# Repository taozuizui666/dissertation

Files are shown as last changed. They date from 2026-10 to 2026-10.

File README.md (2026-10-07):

# **dissertation**

*a self-driving car project based on AI model*

author ： TAO RAN

## 数据训练与模型部署

将采集的操作记录放进根目录 `dataset/`，每行应为 200 个雷达距离加一个操作标签。
正式训练入口为 `software/MLcode/train_model.py`，完成清理、K 特征选择、训练、导出和同步。
K、雷达点数、路径及清理参数集中在脚本顶部。

```bash
python software/MLcode/train_model.py
```

成功后生成 `software/ML_model/randomForest.h` 并备份、同步到
`software/C_code/selfdrive/main/randomForest.h`，打开对应 `main.ino` 编译上传。
模型头文件和训练输出属于生成产物，不手动修改，也不提交到 Git。
首次获取工程时，需要先准备数据并运行训练脚本，生成模型后再编译固件。
本机已配置 `python` 使用 Python 3，并安装用户级训练和 Notebook 依赖。
如需补装全部依赖，在项目根目录执行：

```bash
python -m pip install --user -r software/MLcode/requirements-notebook.txt
```

默认需要 `g++` 校验导出模型。
其他环境的安装和配置详见 [训练说明](software/MLcode/README.md)。

想逐步理解数据如何变成模型，可打开 [教学 Notebook](software/MLcode/training_walkthrough.ipynb)。
选择 `/usr/bin/python3` 内核，逐格运行；默认用临时模拟数据，不覆盖正式模型。

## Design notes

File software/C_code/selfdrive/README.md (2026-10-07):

# Teensy 4.0 自动驾驶程序

在 Arduino IDE 中打开 `main/main.ino`，开发板选择 **Teensy 4.0**，
USB Type 选择 **Serial**，然后编译、上传。

## 文件与依赖

- `main.ino`：读取雷达、提取特征、运行随机森林、控制车轮。
- `Lidar.h` / `Lidar.cpp`：基于 Teensy 数据采集项目的本地雷达驱动，使用
  `Serial2`、115200 波特率和标准 5 字节扫描点协议。
- `control_slide.h` / `control_slide.cpp`：沿用 Teensy 数据采集程序的左右轮
  控制公式及左轮补偿值 10，增加 PWM 的 0–255 限幅。
- `randomForest.h`：训练生成的模型及 `ModelConfig` 输入配置、类别到指令映射。
  由训练脚本同步，不手动修改或提交到 Git；首次编译前需生成该文件。

需要安装 Arduino IDE 的 Teensy 开发板支持包。此项目不需要外部
`RPLidarDriver`、`SoftwareSerial`、SD 或 SPI 库。

## 接线

沿用 `collecting_data/main_lidar_SD_test -teensy -lidar.h/main` 的接线：

| 设备信号 | Teensy 4.0 引脚 |
| --- | --- |
| 雷达 TX | 7（Serial2 RX） |
| 雷达 RX | 8（Serial2 TX） |
| 雷达电机控制 | 9（PWM） |
| 左轮驱动控制 | 14（PWM） |
| 右轮驱动控制 | 15（PWM） |
| 错误指示 LED | 2 |
| 就绪指示 LED | 3 |
| 雷达、车轮驱动器 GND | 与 Teensy GND 共地 |

引脚 0/1 的 `Serial1` 在本程序中未使用，可以保留原来的蓝牙接线，
但本程序不读取蓝牙指令。`Serial` 是电脑 USB 调试接口。
车轮和雷达电机通过已有驱动电路控制；电机供电不能直接接 GPIO。
Teensy 4.0 输入不耐受 5V，UART 信号应与其 3.3V 电平兼容。
参见 [PJRC 串口引脚说明](https://www.pjrc.com/teensy/td_uart.html) 和
[Teensy 4.0 硬件说明](https://www.pjrc.com/store/teensy40.html)。

## 运行与参数

上电时先停止车轮，启动雷达。首次取得全部 K 个有效特征后，自动开始
行驶；无需连接电脑。先架空车轮检查左右轮方向和转向，再落地测试。

`main.ino` 顶部可修改：

| 参数 | 默认值 | 含义 |
| --- | --- | --- |
| `CAR_SPEED` | 100 | 车轮基础 PWM |
| `STEERING_SENSITIVITY` | 2 | Teensy 原采集程序的转向灵敏度 |
| `LIDAR_MOTOR_PWM` | 200 | 雷达电机 PWM |
| `CONTROL_INTERVAL_MS` | 150 | 模型推理和车轮控制间隔 |
| `FEATURE_TIMEOUT_MS` | 500 | 任一模型输入过期后的停车阈值 |

红色/错误指示引脚 2：启动扫描失败时每 500 ms 翻转；特征缺失或
过期时保持高电平。引脚 3：全部模型输入有效且未过期时保持高电平。
启动扫描失败后，检查接线并重启开发板；运行中短暂断流停车后，
全部特征重新有效时自动恢复行驶。
串口监视器每约 500 ms 输出一次 `steering=...`。

## 模型输入约定

分辨率、距离上界、采集扇区、K 和特征索引均读取 `randomForest.h` 的
`ModelConfig`。距离单位为毫米，保持采集程序的整数角度转换。
模型返回类别索引，通过 `ModelConfig::commandForClass()` 转为真实操作指令后
再控制车轮，因此支持训练标签不连续的情况。

在 dissertation 根目录运行 `python3 software/MLcode/train_model.py` 即可重新训练
并同步模型，K 等参数在该脚本顶部修改。详见 [训练说明](../../MLcode/README.md)。
模型头文件属于生成产物，Git 不跟踪；首次获取工程时需要先准备数据并生成模型。

请保持雷达安装方向与训练数据一致。重新训练时，使用 `MLcode/train_model.py`
生成并同步完整模型，确保森林、特征索引及指令映射一起更新。
雷达驱动沿用参考项目的标准扫描协议，不代表支持所有 RPLIDAR 型号。

## 验证

已使用本机 Teensy 1.62.0 开发板支持包，按
`teensy:avr:teensy40:usb=serial` 完整编译通过。
主机模拟测试覆盖扫描响应超时、分段扫描点、无效角度、特征完整性、
数据过期停车、PWM 限幅和 `millis()` 回绕。
尚未执行实物上传和行驶验证，转向效果取决于已有模型和电机标定。

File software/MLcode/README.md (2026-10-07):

# 操作数据训练与部署

正式训练入口是 `train_model.py`，数据清理、K 特征选择、训练、导出及固件同步均由它完成。
全部常用配置集中在文件顶部，用大写常量和中文注释分组。

本机已将 `~/bin/python` 链接到 `/usr/bin/python3`，训练及 Notebook 依赖已安装到
用户级 Python 3 环境。在 dissertation 根目录直接执行：

```bash
python software/MLcode/train_model.py
```

当前终端刷新配置、检查版本及依赖：

```bash
source ~/.bashrc
hash -r
python --version
python -m pip check
```

## 依赖补装

依赖已经安装，正常运行直接使用 `python`。requirements 文件保留用于补装和记录版本范围。
`python -m pip` 使用当前 Python 对应的安装工具。

只补装训练依赖：

```bash
python -m pip install --user -r software/MLcode/requirements.txt
```

训练和 Notebook 的全部依赖：

```bash
python -m pip install --user -r software/MLcode/requirements-notebook.txt
```

`requirements-notebook.txt` 包含 `requirements.txt`，无需分别安装两遍。
需要 Python 3.9 或更新版本、训练依赖和 `g++`。Windows 使用已安装的 Python 3，
并在 `CXX` 配置可用的 GNU C++ 编译器路径。
无编译器时可以显式关闭 `VERIFY_CPP_EXPORT`，报告会标记未执行该检查。
脚本不自动安装依赖，也不自动烧录开发板。

## 逐步学习 Notebook

打开 [training_walkthrough.ipynb](training_walkthrough.ipynb)，在 VS Code 中选择
`/usr/bin/python3` 内核，再从上到下运行单元格。本机已安装 Notebook 依赖，
如需补装，使用上面的 `requirements-notebook.txt` 安装命令。

Notebook 分步展示原始格式、清理统计、X/y、文件分组、ANOVA F 特征评分、K 维输入、
训练与验证、混淆矩阵、最终重训、类别映射、头文件生成和 C++ 预测核对。
它导入正式脚本的函数，并核对展开的训练步骤与正式 `train()` 的结果一致。

默认 `USE_DEMO_DATA=True`，即使 dataset 为空也能运行，并有意加入损坏行展示清理原因。
将其改为 `False` 后读取真实 dataset。两种模式的学习输出均保存在临时目录，不覆盖
正式输出和固件模型。模拟数据的成绩不代表小车效果；正式生成与同步仍使用 `train_model.py`。

## 顶部配置

| 配置 | 默认值 / 作用 |
| --- | --- |
| `K` | 8 个特征 |
| `LIDAR_POINT_COUNT` | 200，必须与采集程序分箱数一致 |
| `INPUT_DIR` | dissertation/dataset，递归读取 `.txt`、`.csv`，不区分扩展名大小写 |
| `OUTPUT_DIR` | software/ML_model |
| `FIRMWARE_HEADER` | software/C_code/selfdrive/main/randomForest.h |
| `USE_FRONT_SECTOR_ONLY` | True，与当前采集程序的扇区限制一致 |
| `MAX_DISTANCE_MM` | 10000，不包含上界 |
| `CLEAN_*` | 整数检查、全零帧过滤、零值比例、文件内去重、录制标签过滤 |
| `TRAIN_LABELS` | 0–15；如需训练直行类别，加入 201 |
| `LABEL_REMAP` | 默认空；`{201: 10}` 将直行并入等效的转向指令 10 |
| `N_ESTIMATORS` / `MAX_DEPTH` | 88 / 3 |
| `TEST_SIZE` / `SPLIT_GAP_ROWS` | 0.2 / 10 |
| `VERIFY_CPP_EXPORT` / `CXX` | 默认用 g++ 编译并核对导出模型 |
| `VERIFY_TEENSY_BUILD` | 默认 False；设 True 并配置 Arduino CLI 后，在覆盖模型前检查整套固件编译 |
| `SYNC_TO_FIRMWARE` | 默认 True，验证成功后备份并同步 |

输入必须无表头，每行是 `d0,d1,...,d199,command`，共 201 列。
末列使用真实蓝牙操作指令，不能通过文件名生成类别。`255` 是开始录制标志，
不作为训练标签；`200` 在当前采集程序中会关闭录制，正常不会写入。
采集只更新索引 0–49 和 151–199，其余列为零，不因这些零删除正常行。
距离数组保留未更新的旧值，记录不是保证全部角度新鲜的完整扫描。
改变分辨率或采集扇区时，需要重新采集对应格式的数据，不能仅修改 Python 配置。

清理报告记录每个文件的列数分布、保留行数和各删除原因。选中特征中的零值默认进一步
排除，以符合固件需要有效距离输入的约定；这一阶段的删除数写入训练报告。

## 运行和输出

```bash
python software/MLcode/train_model.py --k 12
python software/MLcode/train_model.py --clean-only
python software/MLcode/train_model.py --no-sync
```

还可临时指定 `--input-dir`、`--output-dir`、`--firmware-header`。相对路径以
dissertation 为基准，不依赖当前工作目录。输出目录不能放在输入目录内部。

输出包括：

- `randomForest.h`：森林代码、分辨率、扇区、K、原始特征索引、类别到指令映射。
- `data_cleaned.csv`：清理后完整输入，仍是距离列加标签，无表头。
- `clean_report.json`：清理统计。
- `feature_scores.csv`：非常量候选特征的 ANOVA F 分数和选中标志，索引对应原始列。
- `training_report.json`：配置、特征、类别、划分、准确率、混淆矩阵、分类报告、转向容差准确率、导出检查及头文件 SHA-256。
- `randomForest.joblib`：最终 Python 模型及特征、类别配置。
- `backups/<UTC时间>/`：被替换的旧模型，分别保存输出目录和固件目录中的版本。

多文件按文件分组验证，单文件按时间切分并隔开若干相邻帧。特征选择仅使用训练部分；
验证后冻结特征，在全部有效数据上重训最终森林。报告指标来自验证阶段，不是最终森林
在其训练数据上的成绩。如果某类只出现在验证部分，流程报错，需补充采集或调整划分。
将不同独立采集记录保存成不同文件，避免把同一记录的复制件当作独立验证数据。

新头文件直接保存 sklearn 的叶节点类别概率，按森林平均概率预测，保留 `Eloquent::ML::Port::RandomForest`
接口。默认 C++ 检查覆盖数据样本、随机输入和树阈值边界，并核对真实指令与完整概率。
所有检查在临时目录完成，成功后才替换输出及固件模型，写入失败会恢复已替换文件。

根目录 dataset 为空时，不训练或替换模型。`randomForest.h` 和训练输出均为生成产物，
由脚本生成、备份和同步，不手动修改或提交到 Git。`ML_model/` 仅提交目录说明。
首次获取工程时，先准备数据并运行训练脚本，生成完整模型头文件后再编译固件。

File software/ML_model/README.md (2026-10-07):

# 模型输出

运行 `../MLcode/train_model.py` 后，清理数据、特征评分、评估报告、Python 模型及
`randomForest.h` 生成到这里，头文件自动同步到 `../C_code/selfdrive/main/`。
配置和操作说明见 [MLcode/README.md](../MLcode/README.md)。

本目录中的模型、清理数据和评估报告均为生成产物，由脚本管理，不手动修改或提交到 Git。
此目录只提交 README。固件目录中的 `randomForest.h` 同样由训练脚本生成和同步。

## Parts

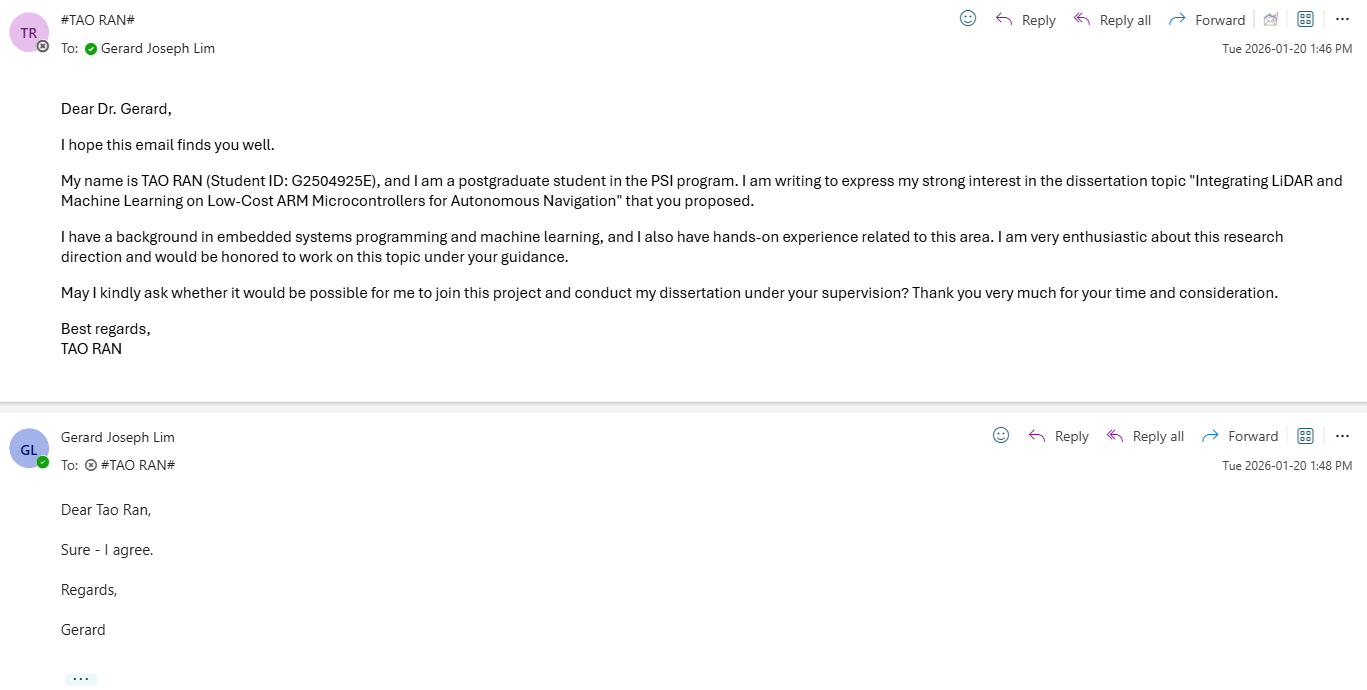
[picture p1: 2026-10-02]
article/TAO RAN_G2504925E_Topic_Integrating LiDAR and Machine Learning on Low-Cost ARM Microcontrollers for Autonomous Navigation.png

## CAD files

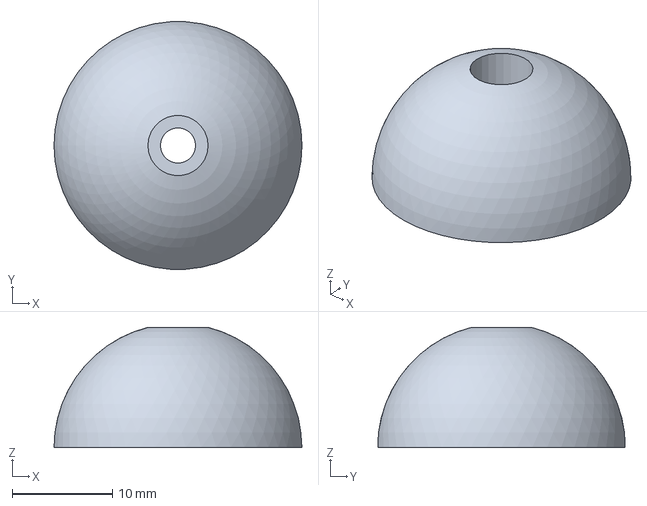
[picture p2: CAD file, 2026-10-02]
hardware/3Dmodels/caster_wheel.3mf
24.7 x 24.7 x 12.0 mm

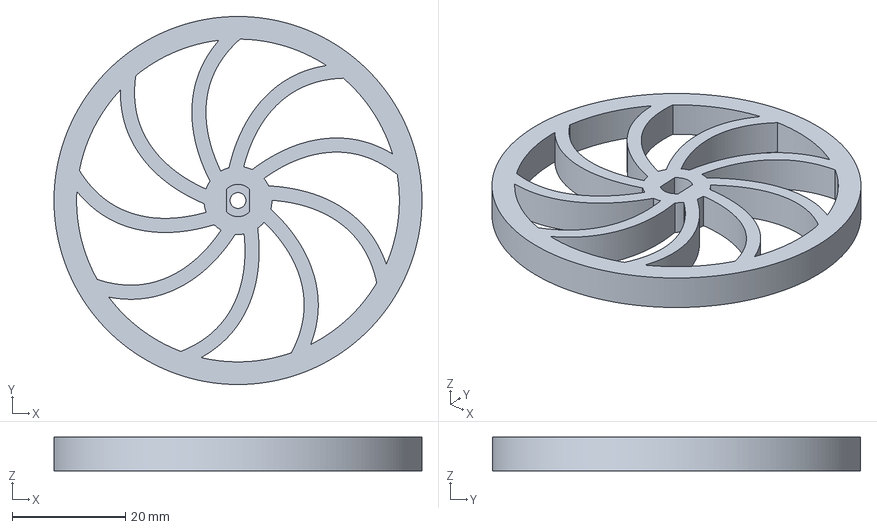
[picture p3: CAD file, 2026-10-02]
hardware/3Dmodels/nikodembartnik-11-tt_motor_wheel.3mf
65.0 x 65.0 x 6.00 mm

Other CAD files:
hardware/3Dmodels/zhijia.gcode.3mf
hardware/3Dmodels/nikodembartnik-48-rplidar_holder.gcode.3mf
hardware/3Dmodels/holder_16pair.gcode.3mf
hardware/3Dmodels/holder.gcode.3mf
hardware/3Dmodels/motor_holder_right.gcode.3mf
hardware/3Dmodels/zhijia2.gcode.3mf

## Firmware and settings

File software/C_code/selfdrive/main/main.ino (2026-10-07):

#include <Arduino.h>
#include "Lidar.h"
#include "control_slide.h"
#include "randomForest.h"

#if !defined(ARDUINO_TEENSY40)
#error "Select Teensy 4.0 in Tools > Board."
#endif

// Same wiring as the Teensy Lidar.h data-collection sketch.
// Lidar TX -> Teensy pin 7 (RX2); Lidar RX -> pin 8 (TX2).
constexpr uint8_t LIDAR_MOTOR_PIN = 9;
constexpr uint8_t LEFT_MOTOR_PIN = 14;
constexpr uint8_t RIGHT_MOTOR_PIN = 15;
constexpr uint8_t ERROR_LED_PIN = 2;
constexpr uint8_t READY_LED_PIN = 3;

constexpr int CAR_SPEED = 100;
constexpr int STEERING_SENSITIVITY = 2;
constexpr uint8_t LIDAR_MOTOR_PWM = 200;
constexpr uint32_t USB_BAUD = 115200;
constexpr uint32_t CONTROL_INTERVAL_MS = 150;
constexpr uint32_t FEATURE_TIMEOUT_MS = 500;
constexpr uint32_t POINT_TIMEOUT_MS = 5;
// Training inputs and class commands travel together with the model header.
constexpr uint16_t LIDAR_RESOLUTION = ModelConfig::LIDAR_RESOLUTION;
constexpr uint16_t MAX_DISTANCE_MM = ModelConfig::MAX_DISTANCE_MM;
constexpr uint16_t FEATURE_COUNT = ModelConfig::FEATURE_COUNT;
constexpr auto &FEATURE_INDICES = ModelConfig::FEATURE_INDICES;

Lidar lidar;
Eloquent::ML::Port::RandomForest classifier;
uint16_t distances[LIDAR_RESOLUTION] = {};
uint32_t featureUpdatedAt[FEATURE_COUNT] = {};
bool featureSeen[FEATURE_COUNT] = {};
bool lidarReady = false;
uint32_t lastControlAt = 0;
uint32_t lastDebugAt = 0;

bool featuresAreFresh(uint32_t now) {
    for (uint16_t i = 0; i < FEATURE_COUNT; ++i) {
        if (!featureSeen[i] ||
            static_cast<uint32_t>(now - featureUpdatedAt[i]) >= FEATURE_TIMEOUT_MS) {
            return false;
        }
    }
    return true;
}

void setup() {
    analogWriteResolution(8);
    pinMode(LIDAR_MOTOR_PIN, OUTPUT);
    pinMode(LEFT_MOTOR_PIN, OUTPUT);
    pinMode(RIGHT_MOTOR_PIN, OUTPUT);
    pinMode(ERROR_LED_PIN, OUTPUT);
    pinMode(READY_LED_PIN, OUTPUT);
    stop_CS(LEFT_MOTOR_PIN, RIGHT_MOTOR_PIN);
    analogWrite(LIDAR_MOTOR_PIN, 0);
    digitalWrite(ERROR_LED_PIN, LOW);
    digitalWrite(READY_LED_PIN, LOW);

    Serial.begin(USB_BAUD);  // USB debug only; never wait for a connected PC.
    Serial2.begin(lidar_baud);
    delay(1000);
    analogWrite(LIDAR_MOTOR_PIN, LIDAR_MOTOR_PWM);
    delay(100);
    lidarReady = lidar.startScan() == RESULT_OK;
    if (!lidarReady) {
        lidar.stop();
        analogWrite(LIDAR_MOTOR_PIN, 0);
    }
    lastControlAt = millis();
}

void loop() {
    if (!lidarReady) {
        stop_CS(LEFT_MOTOR_PIN, RIGHT_MOTOR_PIN);
        digitalWrite(ERROR_LED_PIN, (millis() / 500) % 2);
        return;  // Check wiring and reset the board to retry startup.
    }

    if (lidar.waitPoint(POINT_TIMEOUT_MS) == RESULT_OK) {
        const RPLidarMeasurement &point = lidar.getCurrentPoint();
        if (point.angle >= 0 && point.angle < 360 &&
            point.distance > 0 && point.distance < MAX_DISTANCE_MM &&
            point.quality > 0) {
            // Preserve the original integer-degree binning used during training.
            const uint16_t angle = static_cast<uint16_t>(point.angle);
            const uint16_t index = static_cast<uint16_t>(
                (angle / 360.0f) * LIDAR_RESOLUTION);
            if (ModelConfig::isActiveIndex(index)) {
                distances[index] = static_cast<uint16_t>(point.distance);
                for (uint16_t i = 0; i < FEATURE_COUNT; ++i) {
                    if (FEATURE_INDICES[i] == index) {
                        featureUpdatedAt[i] = millis();
                        featureSeen[i] = true;
                    }
                }
            }
        }
    }

    const uint32_t now = millis();
    if (!featuresAreFresh(now)) {
        stop_CS(LEFT_MOTOR_PIN, RIGHT_MOTOR_PIN);
        digitalWrite(ERROR_LED_PIN, HIGH);
        digitalWrite(READY_LED_PIN, LOW);
        return;
    }
    digitalWrite(ERROR_LED_PIN, LOW);
    digitalWrite(READY_LED_PIN, HIGH);
    if (static_cast<uint32_t>(now - lastControlAt) < CONTROL_INTERVAL_MS) {
        return;
    }
    lastControlAt = now;

    float selectedData[FEATURE_COUNT];
    for (uint16_t i = 0; i < FEATURE_COUNT; ++i) {
        selectedData[i] = distances[FEATURE_INDICES[i]];
    }
    const int command = ModelConfig::commandForClass(classifier.predict(selectedData));
    slide_control(command, CAR_SPEED, LEFT_MOTOR_PIN, RIGHT_MOTOR_PIN,
                  STEERING_SENSITIVITY);

    if (Serial && Serial.availableForWrite() >= 48 &&
        static_cast<uint32_t>(now - lastDebugAt) >= 500) {
        lastDebugAt = now;
        Serial.print("steering=");
        Serial.println(command);
    }
}

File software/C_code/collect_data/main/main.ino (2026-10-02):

#include "Arduino.h"
#include <SPI.h>
#include <SD.h>
#include "control_slide.h"
#include "Lidar.h"
// ports
#define Lidar_TX    7   //teensy RX2
#define Lidar_RX    8   //teensy TX2
#define Lidar_ctr   9   //control the spin speed of lidar
#define CS          10  //chip select(from SD_card module)
#define MOSI        11
#define MISO        12
#define SCK         13  //serial clk(from SD_card module)
#define LEFT_MOTO   14
#define RIGHT_MOTO  15
// paras
#define bluetooth_baud     9600
#define serial_baud        115200
#define V_car       150       // velocity of the car
#define Sensi       2         // sensitivity of control ; bigger than more sensitive


#define time_of_round       120     ////-------------------about 147 ms a round------------------
#define LIDAR_RESOLUTION    200     // the number of data after a round   250
#define degree_90           LIDAR_RESOLUTION/4
#define degree_270          3*LIDAR_RESOLUTION/4

#define NUM_of_yield        50      // how many rounds to yield
#define NUM_to_store        50      // how many rounds to store into SD

//-------------bluetooth----------------
int receive_bt = -1;             // data received from bluetooth

//-------------SD_card------------------
////attention ! File is not FILE
File f;
#define FILE_NAME   "data.txt"

//-------------lidar_data---------------
Lidar rplidar;
uint16_t distances[LIDAR_RESOLUTION];

long last_time = 0;
int flush_counter = 0;
bool is_recording = false;

void setup() {  

  for (int a = 0; a < LIDAR_RESOLUTION; a++) {
    distances[a] = 0;
  }
  // LED   
  pinMode(2, OUTPUT);
  pinMode(3, OUTPUT);
  //-------------pin outputs---------------
  pinMode(Lidar_ctr, OUTPUT);
  pinMode(CS, OUTPUT);
  pinMode(LEFT_MOTO,OUTPUT);
  pinMode(RIGHT_MOTO,OUTPUT); 
  //------------test lidar's data--------
  // Serial.begin(serial_baud);
  //-------------SD_card------------------
  SD.begin(CS);
  // connect to bluetooth
  Serial1.begin(bluetooth_baud);
  //-------------Lidar---------------------
  //// connect RX2/TX2 to lidar's RX/TX
  Serial2.begin(lidar_baud);
  delay(1000);
  if(rplidar.startScan()==0){
    digitalWrite(3, HIGH);
    analogWrite(Lidar_ctr, 200); 
    delay(100);
  }else{
    // digitalWrite(2, HIGH);
    while (1){
      digitalWrite(3, HIGH);
      delay(500);
      digitalWrite(3, LOW);
      delay(500);
    }
  }
  last_time = millis();
  //-------------end of setup()-----------
}

void loop() {

  //----------------------lidar 数据处理--------------------------------

  while(millis() - last_time <= time_of_round){
    //-------------bluetooth 控制与文件管理----------------
    if(Serial1.available()) {
      receive_bt = Serial1.read();
          if(receive_bt == 255) {
        if (!is_recording) {
          f = SD.open(FILE_NAME, FILE_WRITE);
          if (f) {
            is_recording = true;
            digitalWrite(2, HIGH);
          } 
        }
      } 
      else if(receive_bt == 200) {
        if (is_recording) {
          is_recording = false;
          f.close(); 
          digitalWrite(2, LOW);   
        }
      }    
      slide_control(receive_bt, V_car, LEFT_MOTO, RIGHT_MOTO, Sensi);
    }    
    rplidar.waitPoint();
    uint16_t dist = (uint16_t)rplidar.getCurrentPoint().distance;
    uint16_t angl = (uint16_t)rplidar.getCurrentPoint().angle;
    
    int index = (int)((angl / 360.0f) * (float)LIDAR_RESOLUTION);

    if((index<degree_90)||(index>degree_270)){
      if (dist<10000) {
        distances[index] = (uint16_t)dist;
      }else{}
    }
  }
  if(is_recording==true){
    for(int i=0;i<LIDAR_RESOLUTION;i++) {
      f.print(distances[i]);
      f.print(',');
    }
    f.println(receive_bt);
  }else {}
  while (Serial.available()) {
    Serial.read();
  }
  last_time = millis();
  //---------------------end of loop-------------------------
}

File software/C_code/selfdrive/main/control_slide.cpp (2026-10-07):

#include "control_slide.h"

// Preserve the motor calibration and steering formula of the Teensy
// collecting_data sketch, rather than the UNO's different calibration.
constexpr int MOTOR_BIAS = 10;

static int pwmValue(int value) {
    return constrain(value, 0, 255);
}

void stop_CS(int left_moto, int right_moto) {
    analogWrite(left_moto, 0);
    analogWrite(right_moto, 0);
}

void slide_control(int command, int v_car, int left_moto, int right_moto,
                   int sensi) {
    if (command == 200) {
        stop_CS(left_moto, right_moto);
    } else if (command == 201) {
        analogWrite(left_moto, pwmValue(v_car + MOTOR_BIAS));
        analogWrite(right_moto, pwmValue(v_car));
    } else if (command == 255) {
        // Existing recording command does not change the motor outputs.
        return;
    } else if (command >= 0 && command <= 15) {
        const int steering = (10 - command) * sensi;
        analogWrite(left_moto, pwmValue(MOTOR_BIAS + v_car - steering));
        analogWrite(right_moto, pwmValue(v_car + steering));
    } else {
        stop_CS(left_moto, right_moto);
    }
}

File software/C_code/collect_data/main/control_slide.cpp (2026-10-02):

#include "core_pins.h"
#include "control_slide.h"
#define bias    10
void stop_CS(int left_moto,int right_moto)
{
    analogWrite(left_moto, 0);
    analogWrite(right_moto, 0);    
}

void ahead_CS(int v_car,int left_moto,int right_moto)
{
    analogWrite(left_moto, v_car + bias);
    analogWrite(right_moto, v_car);
}

void slide_control(int receive_bt,int v_car,int left_moto,int right_moto,int sensi)
{
    switch(receive_bt){
        case 200:
            stop_CS(left_moto,right_moto);
            break;
        case 201:
            ahead_CS(v_car,left_moto,right_moto);
            break;
        case 255:
            break; // start SD store
        default:
            analogWrite(left_moto,bias + v_car-(10-receive_bt)*sensi);
            analogWrite(right_moto, v_car+(10-receive_bt)*sensi);
            break;
    }
}

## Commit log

2026-10-02 init commit
    [caster_wheel.3mf, holder.gcode.3mf, holder_16pair.gcode.3mf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]
2026-10-07 整理项目工程文件
2026-10-07 继续整理工程文件
    [ran.csv]
2026-10-07 删除生成的文件
    [ran.csv]
2026-10-07 用一整套python代码完成数据处理到生成随机森林模型文件
2026-10-07 python依赖需自己安装，不用venv的方案
2026-10-10 修改gitignore
2026-10-11 录制第一个RL训练的仿真视频
2026-10-11 加入参考文献信息
2026-10-11 加入新的参考文献
2026-10-20 新增参考文献
2026-10-20 第一次仿真训练集数据采集
2026-10-20 更改目录架构
2026-10-22 新增四批RL操控的训练集
2026-10-23 修改训练随机森林脚本及文档
2026-10-26 修改目录结构
2026-10-31 非完整初稿
